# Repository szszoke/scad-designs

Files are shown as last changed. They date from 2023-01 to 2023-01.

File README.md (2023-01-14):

# OpenSCAD designs and modules for music gear

This is where I keep my OpenSCAD designs and modules for my music gear

The modules for music gear are really basic, mostly just cubes, but they have the correct dimensions and a label with a name.

I use VS Code for editing with the [OpenSCAD Language Support](https://marketplace.visualstudio.com/items?itemName=Leathong.openscad-language-support) extension.

I then use [OpenSCAD](https://openscad.org/) configured to re-render when the opened file changes.

# Examples
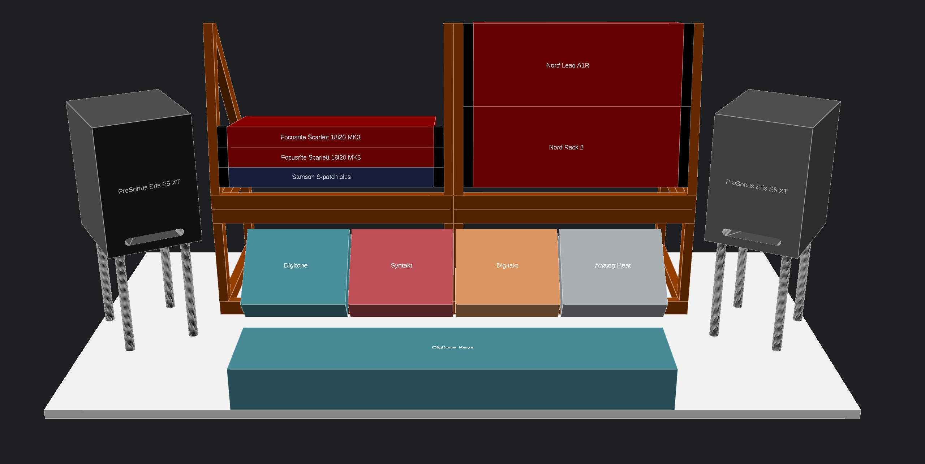
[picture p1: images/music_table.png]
Music table

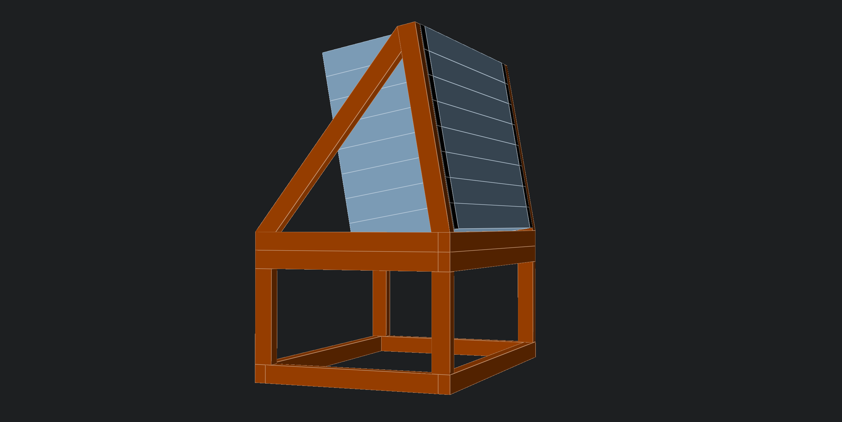
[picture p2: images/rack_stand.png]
19 inch rack unit stand

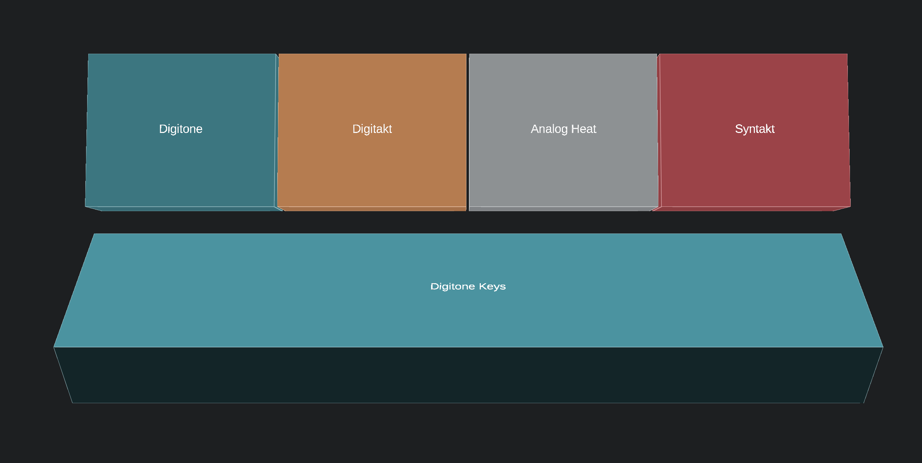
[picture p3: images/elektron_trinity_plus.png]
Elektron trinity and some more


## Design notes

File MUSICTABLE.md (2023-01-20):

# Music table

Music table
19 inch rack unit stand

# Rack enclosure

The rack enclosure has two parts: the riser and the frame for the rack ears. The design assumes the use of 21x33mm lumber. They come in 2400mm and 3000mm lengths where I live.

When the rack enclosure has a tilt, the two frontal beams need to be a bit longer than the actual length in units. Without this the rear corner of the rack ears would have to be dug into the horizontal beam. This offset depends on the tilt angle and can be calculated using the `Law of sines`.

In my design I override this offset to 20mm which would be the result of a tilt of about 30 degrees. I do this because I am not yet sure about the final tilt angle. The good thing is that if I start at 10 degrees and want to go up I will end up cutting my pieces shorter and shorter. At the same time the bigger the tilt the larger the offset is going to be. I know that I will not go higher than 30 degrees so if I start out with a length that would already allow 30 degrees then I can be sure that I will have enough material left for any angle between 0 and 30 degrees.

The rack ear used is an [Adam Hall 19" Parts 61535 B 8](https://www.adamhall.com/shop/af-en/19-inch-rack-accessories/19-inch-rack-rails/943/61535-b-8) which is about 22mm wide with some rounding.

## BOM for two rack enclosures

This BOM assumes that the pieces are cut from a 2400mm long piece. 5mm extra is added to the length of each item when trying to divide up lumber between them to account for the width of the saw blade and the occasional mistake. Everything .5 and above is rounded up to the nearest millimeter.

| Length | Count | Remarks |
| --- | ----- | --- |
| 191mm  | 8 | 90 degree ends |
| 328mm  | 4 | 90 degree ends |
| 349mm  | 8 | 90 degree ends |
| 376mm  | 4 | 10 degree across the long side on one end |
| 455mm  | 4 | 36.8 degree acros the long side on one end and 43.2 on the other |
| 537mm  | 8 | 90 degree ends |

<table>
  <thead>
    <tr>
      <th>Lumber</th>
      <th>Cut length</th>
      <th>Count</th>
      <th>Total length</th>
      <th>Lefrover lumber</th>
      <th>Remarks</th>
    </tr>
  </thead>
  <tbody>
    <tr>
      <td rowspan="2">#1</td>
      <td>191mm</td>
      <td>7</td>
      <td>1337+35mm</td>
      <td>1028mm</td>
      <td>90 degree ends</td>
    </tr>
    <tr>
      <td>328mm</td>
      <td>3</td>
      <td>984+15</td>
      <td>29mm</td>
      <td>90 degree ends</td>
    </tr>
    <tr>
      <td rowspan="3">#2</td>
      <td>191mm</td>
      <td>1</td>
      <td>191+5mm</td>
      <td>2204mm</td>
      <td>90 degree ends</td>
    </tr>
    <tr>
      <td>328mm</td>
      <td>1</td>
      <td>328+5mm</td>
      <td>1871mm</td>
      <td>90 degree ends</td>
    </tr>
    <tr>
      <td>455mm</td>
      <td>4</td>
      <td>1820+20mm</td>
      <td>31mm</td>
      <td>36.8 degree acros the long side on one end and 43.2 on the other</td>
    </tr>
    <tr>
      <td rowspan="2">#3</td>
      <td>376mm</td>
      <td>4</td>
      <td>1504+20mm</td>
      <td>876mm</td>
      <td>10 degree across the long side on one end</td>
    </tr>
    <tr>
      <td>349mm</td>
      <td>1</td>
      <td>349+5mm</td>
      <td>522mm</td>
      <td>90 degree ends</td>
    </tr>
    <tr>
      <td>#4</td>
      <td>537mm</td>
      <td>4</td>
      <td>2148+20mm</td>
      <td>232mm</td>
      <td>90 degree ends</td>
    </tr>
    <tr>
      <td rowspan="2">#5</td>
      <td>537mm</td>
      <td>3</td>
      <td>1611+15mm</td>
      <td>774mm</td>
      <td>90 degree ends</td>
    </tr>
    <tr>
      <td>349mm</td>
      <td>2</td>
      <td>698+10mm</td>
      <td>66mm</td>
      <td>90 degree ends</td>
    </tr>
    <tr>
      <td rowspan="2">#6</td>
      <td>349mm</td>
      <td>5</td>
      <td>1745+25mm</td>
      <td>630mm</td>
      <td>90 degree ends</td>
    </tr>
    <tr>
      <td>537mm</td>
      <td>1</td>
      <td>537+5mm</td>
      <td>88mm</td>
      <td>90 degree ends</td>
    </tr>
  </tbody>
</table>

### Cutting the pieces to length

I did not want to have to change and then re-adjust the stopper between cuts so I made up the following order. The idea is that once the stopper is set, all pieces for that specific length are cut, sometimes from different pieces of lumber. A total of six 2400mm long pieces of lumber is required.

<table>
  <thead>
    <tr>
      <th>Stopper length</th>
      <th>#</th>
      <th>Lumber #</th>
      <th>Count</th>
    </tr>
  <thead>
  <tbody>
    <tr>
      <td rowspan="2">191mm</td>
      <td>1</td>
      <td>#1</td>
      <td>7</td>
    </tr>
    <tr>
      <td>2</td>
      <td>#2</td>
      <td>1</td>
    </tr>
    <tr>
      <td rowspan="2">328mm</td>
      <td>3</td>
      <td>#1</td>
      <td>3</td>
    </tr>
    <tr>
      <td>4</td>
      <td>#2</td>
      <td>1</td>
    </tr>
    <tr>
      <td rowspan="1">455mm</td>
      <td>5</td>
      <td>#2</td>
      <td>4</td>
    </tr>
    <tr>
      <td rowspan="1">376mm</td>
      <td>6</td>
      <td>#3</td>
      <td>4</td>
    </tr>
    <tr>
      <td rowspan="3">349mm</td>
      <td>7</td>
      <td>#3</td>
      <td>1</td>
    </tr>
    <tr>
      <td>8</td>
      <td>#5</td>
      <td>2</td>
    </tr>
    <tr>
      <td>9</td>
      <td>#6</td>
      <td>5</td>
    </tr>
    <tr>
      <td rowspan="3">537mm</td>
      <td>10</td>
      <td>#4</td>
      <td>4</td>
    </tr>
    <tr>
      <td>11</td>
      <td>#5</td>
      <td>3</td>
    </tr>
    <tr>
      <td>12</td>
      <td>#6</td>
      <td>1</td>
    </tr>
  </tbody>
</table>

### Cutting the angled pieces

1. Adjust the cutting angle to 10 degress off and adjust the stopper for the 376mm piece
2. Turn the piece so that the angled end goes across the long side
3. Cut the 376mm pieces
4. Adjust the cutting angle to 36.8 off and adjust the stopper for the 455mm piece
5. Turn the piece so that the angled end goes across the long side
6. Cut the 455mm pieces
7. Adjust the angle to 43.2 degrees without changing the stopper
8. Cut the other end of the 455mm pieces, when done, the piece should form a trapezoid

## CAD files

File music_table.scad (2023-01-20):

use <modules/beam.scad>
use <modules/elektron.scad>
use <modules/presonus.scad>
use <modules/rack.scad>
use <modules/rotate.scad>

tabletop_width = 1600;
tabletop_depth = 800;
tabletop_height = 20;

frame_beam_long_side = 33;
frame_beam_short_side = 21;

rack_max_units = 8;
rack_tilt_angle = 10;
rack_depth = 370;
rack_ear_width = 22;

speaker_angle = 30;

module tabletop() {
  color("white") translate([ 0, 0, -tabletop_height ])
      cube([ tabletop_width, tabletop_depth, tabletop_height ]);
}

module speakers() {
  speaker_width = presonus_eris_e5xt_width();
  speaker_height = presonus_eris_e5xt_height();
  speaker_depth = presonus_eris_e5xt_depth();

  speaker_center =
      [ speaker_width / 2, speaker_depth / 2, speaker_height / 2 ];

  module speaker_on_stand() {
    put_on_stand(height = 230) presonus_eris_e5xt();
  }

  color("#525252") translate([ 20, 250, 0 ])
      rotate_about(a = speaker_angle, pv = speaker_center)
          speaker_on_stand();

  color("#525252")
      translate([ tabletop_width - speaker_width - 20, 250, 0 ])
          rotate_about(a = -speaker_angle, pv = speaker_center)
              speaker_on_stand();
}

module elektron_boxes() {
  spacing = 5;
  function x_offset(i) = i * (digi_box_width() + spacing);

  digitone();
  translate(v = [ x_offset(1), 0, 0 ]) syntakt();
  translate(v = [ x_offset(2), 0, 0 ]) digitakt();
  translate(v = [ x_offset(3), 0, 0 ]) analog_heat();
}

rack_enclosure_width =
    rack_unit_width() + 2 * (frame_beam_short_side + rack_ear_width);

module rack_enclosures(spacing_from_surface) {
  translate(v = [ 0, tabletop_depth - rack_depth, 0 ]) {
    rack_enclosure(units = rack_max_units,
                   tilt_angle = rack_tilt_angle, depth = rack_depth,
                   override_tilt_offset = 20,
                   rack_ear_width = rack_ear_width,
                   spacing_from_surface = spacing_from_surface,
                   beam_long_side = frame_beam_long_side,
                   beam_short_side = frame_beam_short_side,
                   frame_color = "#9c4000") {
      translate([ 0, 0, start_at_unit(2) ]) rack_instrument(
          units = 1, depth = 230, rack_ear_width = rack_ear_width,
          c = "#900", label = "Focusrite Scarlett 18i20 MK3");
      translate([ 0, 0, start_at_unit(1) ]) rack_instrument(
          units = 1, depth = 230, rack_ear_width = rack_ear_width,
          c = "#900", label = "Focusrite Scarlett 18i20 MK3");

      rack_instrument(units = 1, depth = 70,
                      rack_ear_width = rack_ear_width, c = "#232f59",
                      label = "Samson S-patch plus");
    }

    translate([ rack_enclosure_width, 0, 0 ]) rack_enclosure(
        units = rack_max_units, tilt_angle = rack_tilt_angle,
        depth = rack_depth, override_tilt_offset = 20,
        rack_ear_width = rack_ear_width,
        spacing_from_surface = spacing_from_surface,
        beam_long_side = frame_beam_long_side,
        beam_short_side = frame_beam_short_side,
        frame_color = "#9c4000") {
      rack_instrument(units = 4, depth = 100,
                      rack_ear_width = rack_ear_width, c = "#900",
                      label = "Nord Rack 2");
      translate([ 0, 0, start_at_unit(4) ]) rack_instrument(
          units = 4, depth = 100, rack_ear_width = rack_ear_width,
          c = "#900", label = "Nord Lead A1R");
    }
  }
}

tabletop();
speakers();

translate([ (tabletop_width - 2 * rack_enclosure_width) / 2, 0, 0 ])
    rack_enclosures(290);

translate([
  (tabletop_width - 4 * digi_box_width() - 10) / 2, 210,
  digitone_keys_height() + 10
]) rotate(a = [ 40, 0, 0 ]) elektron_boxes();

translate([ (tabletop_width - digitone_keys_width()) / 2, 0, 0 ])
    digitone_keys();

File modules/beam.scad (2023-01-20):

nothing = 0.01;

module beam(length, long_side, short_side, a_start_short,
            a_start_long, a_stop_short, a_stop_long) {
  echo(str("BOM:beam:length=", length, ",long_side=", long_side,
           ",short_side=", short_side, ",a_start_short=", a_start_short,
           ",a_start_long=", a_start_long, ",a_stop_short=",
           a_stop_short, ",a_stop_long=", a_stop_long));
  difference() {
    cube([ length, long_side, short_side ]);

    /*
      make the ends angled by subtracting a triangle from them

         a        b        c
      ------ = ------ = ------
      sin(A)   sin(B)   sin(C)
              B
             /\
          c /  \ a
           /    \
        A /______\ C
              b

      two angles and a side is always known
      - the corner angle which is always 90
      - the angle parameter
      - the length of the side which is going to be angled
    */

    if (!is_undef(a_start_short)) {
      /*
        A angle is 90
        B angle is 90 - a_start_short
        C angle is a_start_short
        c side is short_side
        b side length is missing

        b = c * sin(C) / sin(B)
      */

      b_length =
          short_side * sin(a_start_short) / sin(90 - a_start_short);

      if (a_start_short > 0) {
        translate([ -nothing, long_side + nothing, -nothing ])
            rotate([ 90, 0, 0 ])
                linear_extrude(long_side + 2 * nothing)
                    polygon(points = [
                      [ -nothing, 0 ], [ 0, short_side - nothing ],
                      [ b_length + nothing, -nothing ]
                    ]);
      } else {
        translate([ -nothing, -nothing, short_side + nothing ])
            rotate([ -90, 0, 0 ])
                linear_extrude(long_side + 2 * nothing)
                    polygon(points = [
                      [ -nothing, short_side ],
                      [ -b_length, -nothing ], [ 0, -nothing ]
                    ]);
      }
    } else if (!is_undef(a_start_long)) {
      /*
        A angle is 90
        B angle is 90 - a_start_long
        C angle is a_start_long
        c side is long_side
        b side length is missing

        b = c * sin(C) / sin(B)
      */

      b_length =
          long_side * sin(a_start_long) / sin(90 - a_start_long);

      if (a_start_long > 0) {
        translate([ -nothing, -nothing, -nothing ])
            linear_extrude(short_side + 2 * nothing)
                polygon(points = [
                  [ -nothing, 0 ], [ 0, long_side - nothing ],
                  [ b_length + nothing, -nothing ]
                ]);
      } else {
        translate([ -nothing, 0, -nothing ])
            linear_extrude(short_side + 2 * nothing)
                polygon(points = [
                  [ -b_length, long_side + nothing ], [ 0, 0 ],
                  [ 0, long_side + nothing ]
                ]);
      }
    }

    if (!is_undef(a_stop_short)) {
      /*
        A angle is 90
        B angle is 90 - a_stop_short
        C angle is a_stop_short
        c side is short_side
        b side length is missing

        b = c * sin(C) / sin(B)
      */

      b_length =
          short_side * sin(a_stop_short) / sin(90 - a_stop_short);

      if (a_stop_short > 0) {
        translate([ 0, long_side + nothing, 0 ]) rotate([ 90, 0, 0 ])
            linear_extrude(long_side + 2 * nothing) polygon(
                points = [[length + nothing, 0],
                          [length + nothing, short_side + nothing],
                          [length - b_length + nothing,
                           short_side + nothing]]);
      } else {
        translate([ 0, long_side + nothing, -nothing ]) rotate(
            [ 90, 0, 0 ]) linear_extrude(long_side + 2 * nothing)
            polygon(points =
                        [[length + b_length, 0],
                         [length + nothing, 0],
                         [length + nothing, short_side + nothing]]);
      }
    } else if (!is_undef(a_stop_long)) {
      /*
        A angle is 90
        B angle is 90 - a_stop_long
        C angle is a_stop_long
        c side is long_side
        b side length is missing

        b = c * sin(C) / sin(B)
      */

      b_length = long_side * sin(a_stop_long) / sin(90 - a_stop_long);

      if (a_stop_long > 0) {
        translate([ 0, 0, -nothing ])
            linear_extrude(short_side + 2 * nothing) polygon(
                points = [[length - b_length, long_side + nothing],
                          [length + nothing, -nothing],
                          [length + nothing, long_side + nothing]]);
      } else {
        translate([ 0, 0, -nothing ])
            linear_extrude(short_side + 2 * nothing) polygon(
                points = [[length + b_length, -nothing],
                          [length + nothing, -nothing],
                          [length + nothing, long_side + nothing]]);
      }
    }
  }
}

beam(length = 100, long_side = 33, short_side = 22,
     a_start_short = 30, a_stop_short = 30);

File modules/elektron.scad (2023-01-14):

function digi_box_width() = 215;
function digi_box_height() = 176;
function digi_box_depth() = 63;

module digi(box_color, label) {
  width = digi_box_width();
  depth = digi_box_height();
  height = digi_box_depth();

  union() {
    color(box_color) cube([ width, depth, height ]);

    if (label) {
      translate([ width / 2, depth / 2, height ]) color("white")
          text(label, halign = "center", valign = "center");
    }
  }
}

module digitone() { digi("#4a919e", "Digitone"); }

module syntakt() { digi("#bf5258", "Syntakt"); }

module digitakt() { digi("#df9863", "Digitakt"); }

module analog_heat() { digi("#adb2b5", "Analog Heat"); }

function digitone_keys_width() = 870;
function digitone_keys_height() = 90;
function digitone_keys_depth() = 180;

module digitone_keys() {
  width = digitone_keys_width();
  height = digitone_keys_height();
  depth = digitone_keys_depth();

  union() {
    color("#4a919e") cube([ width, depth, height ]);
    translate([ width / 2, depth / 2, height ]) color("white")
        text("Digitone Keys", halign = "center", valign = "center");
  }
}

translate(v = [ 0, 220, 90 ]) rotate(a = [ 45, 0, 0 ]) {
  digitone();

  translate(v = [ 215 + 3.33, 0, 0 ]) digitakt();

  translate(v = [ 215 * 2 + 3.33 * 2, 0, 0 ]) analog_heat();

  translate(v = [ 215 * 3 + 3.33 * 3, 0, 0 ]) syntakt();
}

digitone_keys();

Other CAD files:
modules/math.scad
modules/presonus.scad
modules/rack.scad
modules/rotate.scad

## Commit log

2023-01-14 add initial modules
    [beam.scad, elektron.scad, math.scad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]
2023-01-14 add music table
    [music_table.scad]
2023-01-14 add color parameter to rack_enclosure module
    [rack.scad]
2023-01-14 change some colors in music_table
    [music_table.scad]
2023-01-14 remove nothing variable from music_table
    [music_table.scad]
2023-01-14 rename table_ to tabletop_ in music_table
    [music_table.scad]
2023-01-14 clean up music_table a bit
    [music_table.scad]
2023-01-15 add bom for music table
2023-01-20 consider clearance for angled rack ears
    [rack.scad]
2023-01-20 use reald-world angle for elektron boxes
    [music_table.scad]
2023-01-20 add nord rack 2
    [music_table.scad]
2023-01-20 add override_tilt_offset to rack module
    [rack.scad]
2023-01-20 support custom rack ear width in rack module
    [rack.scad]
2023-01-20 make some adjustments after parts arrived
    [music_table.scad]
2023-01-20 echo beam properties useful for bill of materials
    [beam.scad]
2023-01-20 round up millimeters
